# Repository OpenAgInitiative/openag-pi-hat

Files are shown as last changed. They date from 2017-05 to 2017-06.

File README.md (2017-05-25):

# openag-pi-hat
This hat is a simple connector breakout board to simplify the wiring on the brain box. It is the first step toward a more comprehensive brain box PCB. 

## Board
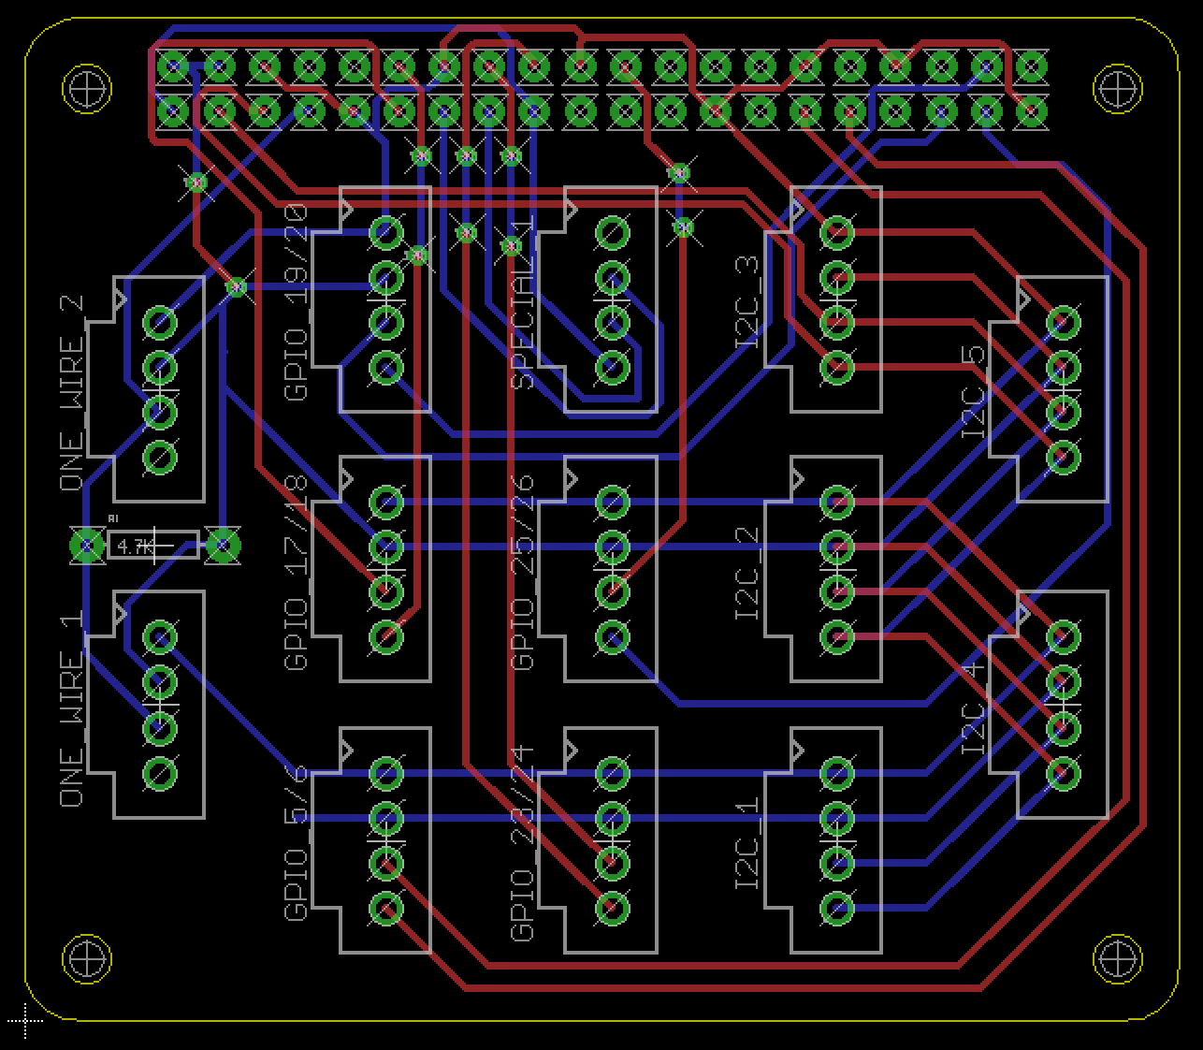
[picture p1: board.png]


## Schematic
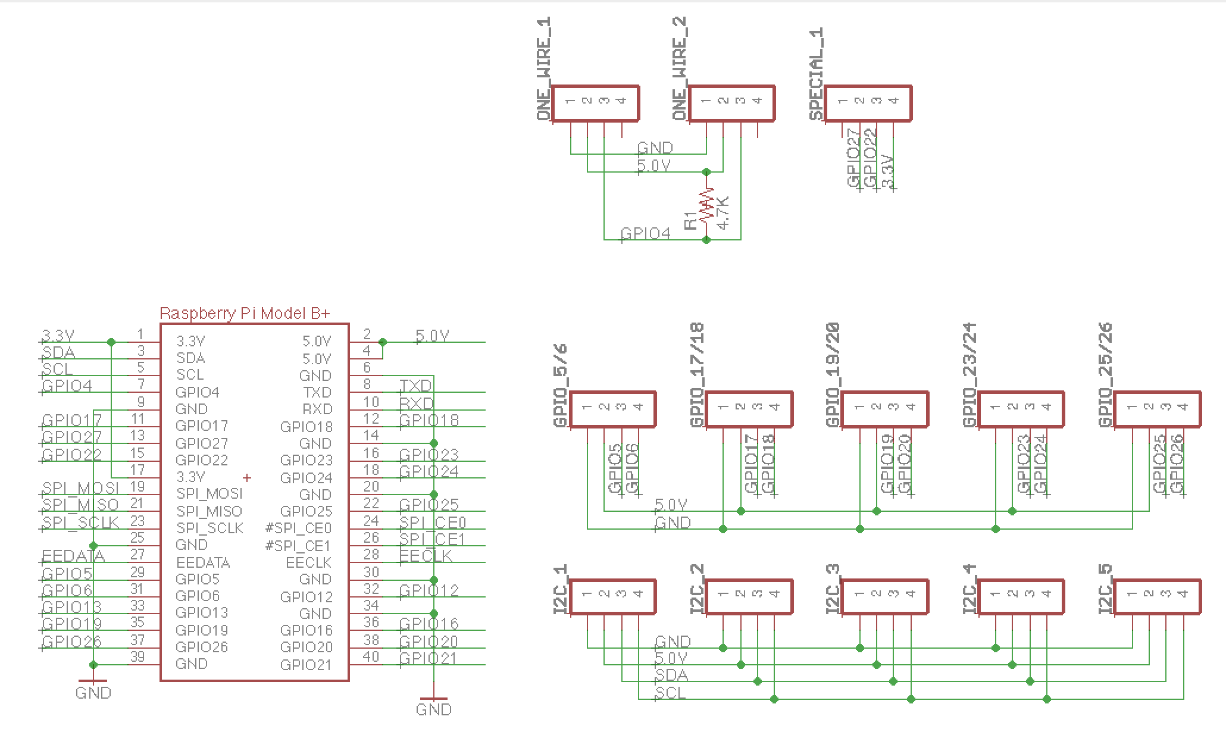
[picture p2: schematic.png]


## Fabrication Instructions
1. Gerber files are included in this repo, send them to a pcb fab house. Use OSH Park for low volume / low cost. Use Advanced Circuits for high volume / fast turn time.
2. Bill of materials can be found in the repo, order as needed
3. Solder components to the PCB

## Adafruit-Perma-Proto-HAT-PCB README
This repo was forked from the Adafruit-Perma-Proto-HAT-PCB
```
Format is EagleCAD schematic and board layout

For more details, check out the product page at

-----> https://www.adafruit.com/products/2310

-----> https://www.adafruit.com/products/2314

Adafruit invests time and resources providing this open source design, 
please support Adafruit and open-source hardware by purchasing 
products from Adafruit!

Designed by Adafruit Industries.  
Creative Commons Attribution, Share-Alike license, check license.txt for more information
All text above must be included in any redistribution
```

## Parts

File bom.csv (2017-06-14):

Qty | Description | Unit Cost | Sum Cost | Link
13 | CONN HEADER 4POS .100 VERT GOLD | 0.94 | 12.22 | https://www.digikey.com/products/en?keywords=0705430003
13 | CONN TERM BLOCK 2.54MM 4POS PCB | 1.38 | 17.94 | https://www.digikey.com/product-detail/en/on-shore-technology-inc/OSTVN04A150/ED10563-ND/1588864
1 | GPIO Stacking Header for Pi A+/B+/Pi 2/Pi 3 - Extra-long 2x20 Pins | 2.50 | 2.50 | https://www.adafruit.com/product/2223
1 | Brass M2.5 Standoffs for Pi HATs - Black Plated - Pack of 2 | 0.75 | 0.75 | https://www.adafruit.com/product/2336
1 | RES 4.7K OHM 1/8W 5% CF AXIAL | 0.10 | 0.10 | https://www.digikey.com/product-detail/en/stackpole-electronics-inc/CF18JT4K70/CF18JT4K70CT-ND/2022758

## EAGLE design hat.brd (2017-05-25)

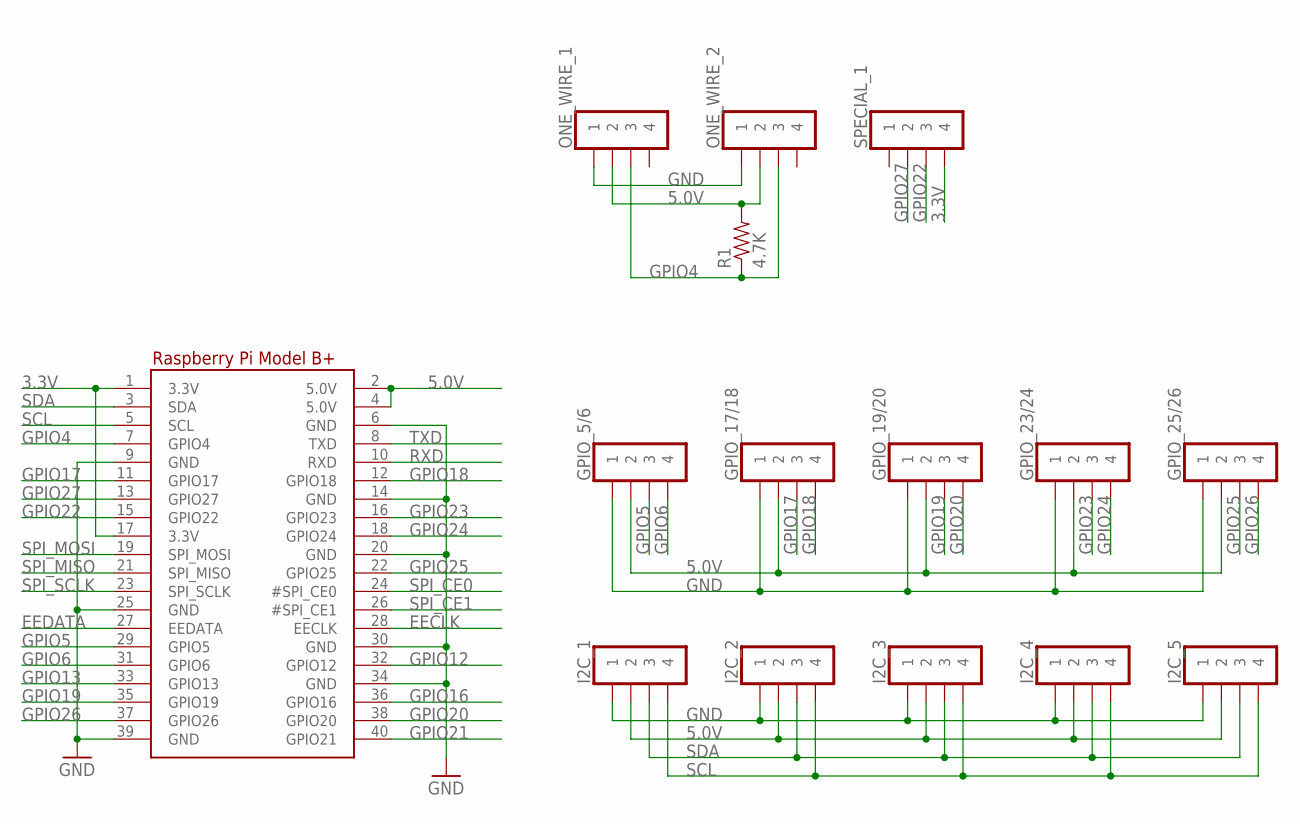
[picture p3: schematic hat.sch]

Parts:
GPIO_5/6, GPIO_17/18, GPIO_19/20, GPIO_23/24, GPIO_25/26: MOLEX_0705430003
I2C_1, I2C_2, I2C_3, I2C_4, I2C_5: MOLEX_0705430003
ONE_WIRE_1, ONE_WIRE_2: MOLEX_0705430003
R1: 4.7K; AXIAL-0.3
RPI1: RASPBERRYPI_BPLUS_HATNOSLOTS; PI_HAT_NOSLOTS
SPECIAL_1: MOLEX_0705430003

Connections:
3.3V: RPI1.1 (3.3V), RPI1.17 (3.3V), SPECIAL_1.4
5.0V: GPIO_5/6.2, GPIO_17/18.2, GPIO_19/20.2, GPIO_23/24.2, GPIO_25/26.2, I2C_1.2, I2C_2.2, I2C_3.2, I2C_4.2, I2C_5.2, ONE_WIRE_1.2, ONE_WIRE_2.2, R1.P$2 (2), RPI1.2 (5.0V), RPI1.4 (5.0V)
EECLK: RPI1.28 (EECLK)
EEDATA: RPI1.27 (EEDATA)
GND: GPIO_5/6.1, GPIO_17/18.1, GPIO_19/20.1, GPIO_23/24.1, GPIO_25/26.1, I2C_1.1, I2C_2.1, I2C_3.1, I2C_4.1, I2C_5.1, ONE_WIRE_1.1, ONE_WIRE_2.1, RPI1.6 (GND), RPI1.9 (GND), RPI1.14 (GND), RPI1.20 (GND), RPI1.25 (GND), RPI1.30 (GND), RPI1.34 (GND), RPI1.39 (GND)
GPIO4: ONE_WIRE_1.3, ONE_WIRE_2.3, R1.P$1 (1), RPI1.7 (GPIO4)
GPIO5: GPIO_5/6.3, RPI1.29 (GPIO5)
GPIO6: GPIO_5/6.4, RPI1.31 (GPIO6)
GPIO12: RPI1.32 (GPIO12)
GPIO13: RPI1.33 (GPIO13)
GPIO16: RPI1.36 (GPIO16)
GPIO17: GPIO_17/18.3, RPI1.11 (GPIO17)
GPIO18: GPIO_17/18.4, RPI1.12 (GPIO18)
GPIO19: GPIO_19/20.3, RPI1.35 (GPIO19)
GPIO20: GPIO_19/20.4, RPI1.38 (GPIO20)
GPIO21: RPI1.40 (GPIO21)
GPIO22: RPI1.15 (GPIO22), SPECIAL_1.3
GPIO23: GPIO_23/24.3, RPI1.16 (GPIO23)
GPIO24: GPIO_23/24.4, RPI1.18 (GPIO24)
GPIO25: GPIO_25/26.3, RPI1.22 (GPIO25)
GPIO26: GPIO_25/26.4, RPI1.37 (GPIO26)
GPIO27: RPI1.13 (GPIO27), SPECIAL_1.2
RXD: RPI1.10 (RXD)
SCL: I2C_1.4, I2C_2.4, I2C_3.4, I2C_4.4, I2C_5.4, RPI1.5 (SCL)
SDA: I2C_1.3, I2C_2.3, I2C_3.3, I2C_4.3, I2C_5.3, RPI1.3 (SDA)
SPI_CE0: RPI1.24 (#SPI_CE0)
SPI_CE1: RPI1.26 (#SPI_CE1)
SPI_MISO: RPI1.21 (SPI_MISO)
SPI_MOSI: RPI1.19 (SPI_MOSI)
SPI_SCLK: RPI1.23 (SPI_SCLK)
TXD: RPI1.8 (TXD)

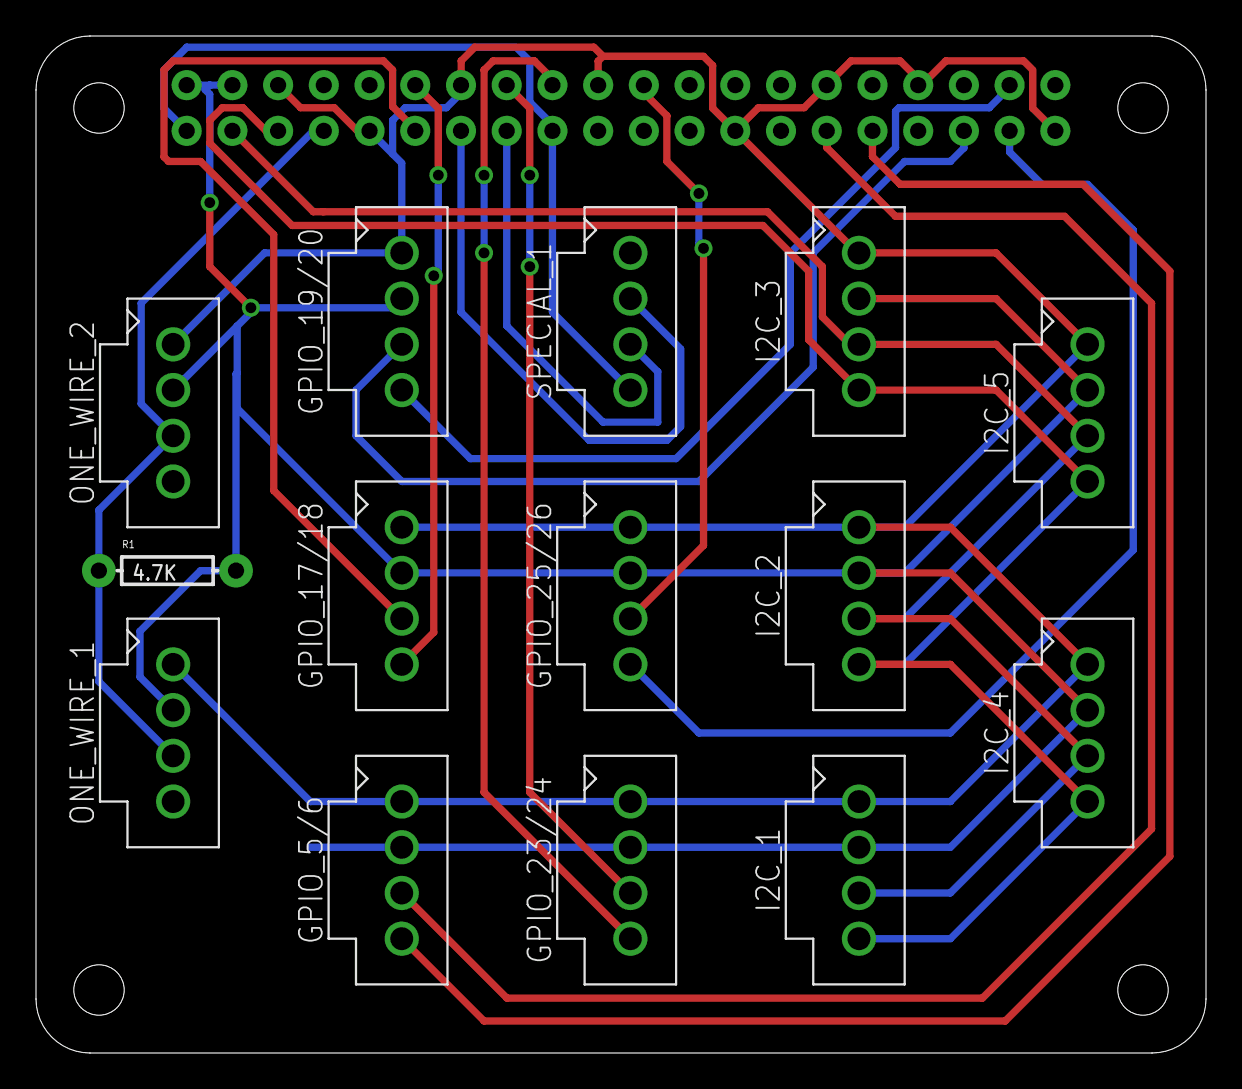
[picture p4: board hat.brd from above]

Board: 2 copper layers, 65.0 x 56.5 mm, 15 parts (0 on the bottom side), 18 nets.

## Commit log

2017-05-23 Rename Adafruit HaD Proto HAT rev A.brd to hat_template.brd
    [hat_template.brd]
2017-05-23 Rename Adafruit HaD Proto HAT rev A.sch to hat_template.sch
    [hat_template.sch]
2017-05-25 simple connector breakout board
    [hat.brd, hat.sch, hat_template.brd]

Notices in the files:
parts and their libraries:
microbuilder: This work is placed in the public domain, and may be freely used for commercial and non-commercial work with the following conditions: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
